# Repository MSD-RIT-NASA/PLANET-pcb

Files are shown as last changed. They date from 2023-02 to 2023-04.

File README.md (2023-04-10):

 

<!-- PROJECT SHIELDS -->
<!--
*** I'm using markdown "reference style" links for readability.
*** Reference links are enclosed in brackets [ ] instead of parentheses ( ).
*** See the bottom of this document for the declaration of the reference variables
*** for contributors-url, forks-url, etc. This is an optional, concise syntax you may use.
*** https://www.markdownguide.org/basic-syntax/#reference-style-links
-->

<!-- PROJECT LOGO -->
<br />
<div align="center">
  <a href="">
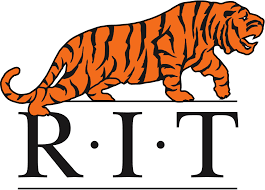
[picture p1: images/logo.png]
    
  </a>

  <h3 align="center">PLANETS PCB</h3>

  <p align="center">
    The pcb for the connector board. This is to negate the excess use of wires and fit snuggly into the case.
  </p>
</div>

<!-- TABLE OF CONTENTS -->
<details>
  <summary>Table of Contents</summary>
  <ol>
    <li>
      <a href="#about-the-project">About The Project</a>
      <ul>
        <li><a href="#built-with">Built With</a></li>
      </ul>
    </li>
    <li><a href="#Component List">Component List</a></li>
    <li><a href="#block-diagram">Block Diagram</a></li>
    <li><a href="#schematic">Schematic</a></li>
    <li><a href="#pcb-layout">PCB Layout</a></li>
    <li><a href="#dimensions">Dimensions</a></li>
    <li><a href="#order details">Order Details</a></li>
    <li><a href="#contact">Contact</a></li>
  </ol>
</details>

<!-- ABOUT THE PROJECT -->
## About the Project

Project Link: [https://github.com/MSD-RIT-NASA](https://github.com/MSD-RIT-NASA)

This PCB was created for the intention to be used with the Gamification and Performanced Based Monitoring of Sensorimotor Activities project with NASA. This project, also known as PLANETs, is being developed by a Multidiciplinary Team at RIT. The objective of the project is to train an astronauts sense of blance when they return from long suspended time in space or to adapt themselves to a new planet's gravity. The game was meant to be a fun and competitive way to train the balance and activly collect and calculate data on their performace. These sensors interface with the SlimeVR program to create a skeleton that configures a persons center of balance, and creates a score. Another sensor is used under a balance board to relay the rotation of the board to the game. The game reflects a position back to the player in order to encourage them to adjust the angle of the balance board according to the game. The game awards the adjusted balance with game points, and negates points when they do not accuratly move the board. 

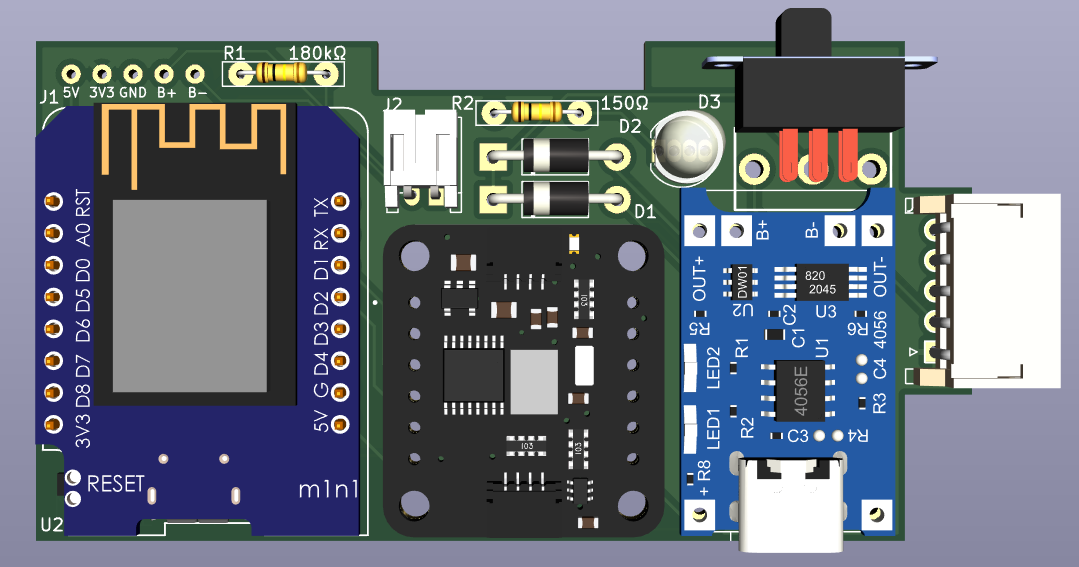
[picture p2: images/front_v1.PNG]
Front of PCB
[]()
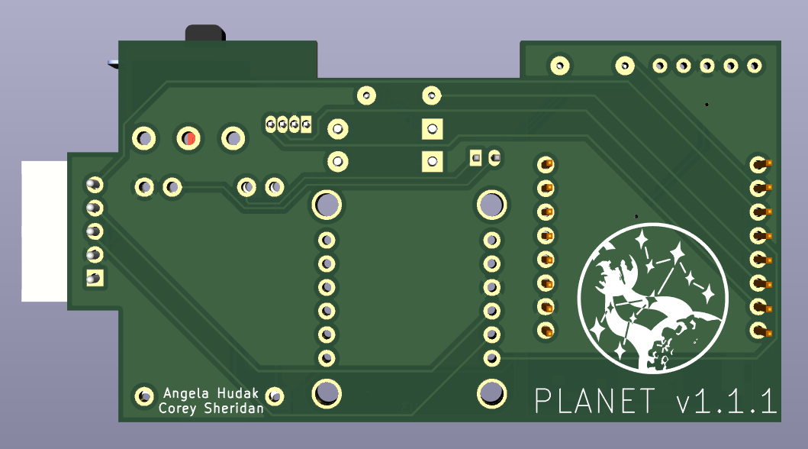
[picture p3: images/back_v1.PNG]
Back of PCB
[]()

<p align="right">(<a href="#top">back to top</a>)</p>

### Built With

The pcb and schematic were designed in KiCad and ordered on JLCPCB

* [KiCad](https://www.kicad.org/)
* [JLCPCB](https://jlcpcb.com/)

<p align="right">(<a href="#top">back to top</a>)</p>

<!-- Component List -->
## Component List

Name | Symbol | Footprint | Purchase Link
--- | --- | --- | ---
RGB LED | Device:LED_RGBK | LED_THT:LED_D5.0mm-4_RGB | [LINK](https://www.sparkfun.com/products/9264)
150Ω | Device:R | 150Ω | [LINK](https://www.amazon.com/BOJACK-Values-Resistor-Resistors-Assortment/dp/B08FD1XVL6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)
180KΩ | Device:R | 180KΩ | [LINK](https://www.digikey.com/en/products/detail/te-connectivity-passive-product/ROX3SJ180K/2390251)
3.7V Lipo Battery| --- | --- | [LINK](https://www.digikey.com/en/products/detail/jauch-quartz/LP503759JU-PCM-2-WIRES-70MM/9560991)
Battery Connector | Connector:Conn_01x02_Female | JST_PH_S2B-PH-K_02x2.00mm_Angled | [LINK](https://www.digikey.com/en/products/detail/jst-sales-america-inc/S2B-PH-K-S-LF-SN/926626) [LINK](https://www.digikey.com/en/products/detail/jst-sales-america-inc/PHR-2/608607)
1N5817 Diode | SlimeVRMotherBoard-cache:Diode_1N5817 | Diode_THT:D_DO-41_SOD81_P10.16mm_Horizontal | [LINK](https://www.digikey.com/en/products/detail/stmicroelectronics/1N5817/770971)
1N5817 Diode | SlimeVRMotherBoard-cache:Diode_1N5817 | Diode_THT:D_DO-41_SOD81_P10.16mm_Horizontal | [LINK](https://www.digikey.com/en/products/detail/stmicroelectronics/1N5817/770971)
TP4056 Type-C | SlimeVRLibrary:4056Board | 4056Board | [LINK](https://www.amazon.com/gp/product/B07PZ6V937/ref=ppx_yo_dt_b_search_asin_title?ie=UTF8&psc=1)
Switch | SlimeVRLibrary:SlideSwitch | Wowoone_Slide_Switch_5mm | [LINK](https://www.amazon.com/gp/product/B07XSJYYYB/ref=ppx_yo_dt_b_search_asin_title?ie=UTF8&psc=1)
D1 mini | wemos_mini:WeMos_D1_mini | wemos-d1-mini-with-pin-header-and-connector | [LINK](https://www.amazon.com/gp/product/B081PX9YFV/ref=ppx_yo_dt_b_asin_title_o02_s00?ie=UTF8&th=1)
BNO085 Sensor | BNO085:4754 | BNO085 | [LINK](https://www.digikey.com/en/products/detail/adafruit-industries-llc/4754/13426653)
BNO085 AUX Sensor Connector | Connector:Conn_01x05_Female | JST_XH_S05B-XH-A_05x2.50mm_Angled | [LINK](https://www.digikey.com/en/products/detail/jst-sales-america-inc./S5B-XH-A-1(LF)(SN)/9961924) [LINK](https://www.digikey.com/en/products/detail/jst-sales-america-inc/XHP-5/1125486)
Status Rail Connector | Connector:Conn_01x05_Female | fivePinConn | ---

<p align="right">(<a href="#top">back to top</a>)</p>

<!-- BLOCK DIAGRAM -->
## Block Diagram
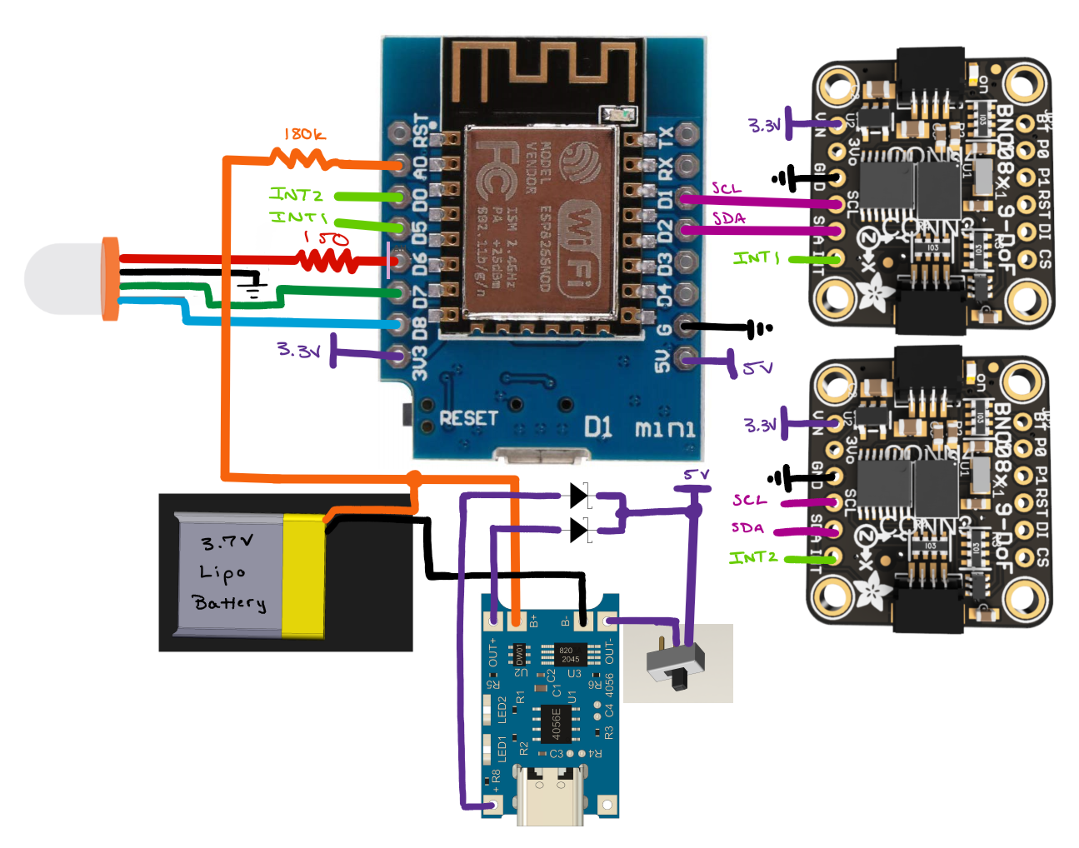
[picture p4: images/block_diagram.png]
Block Diagram
[]()

<!-- SCHEMATIC -->
## Schematic
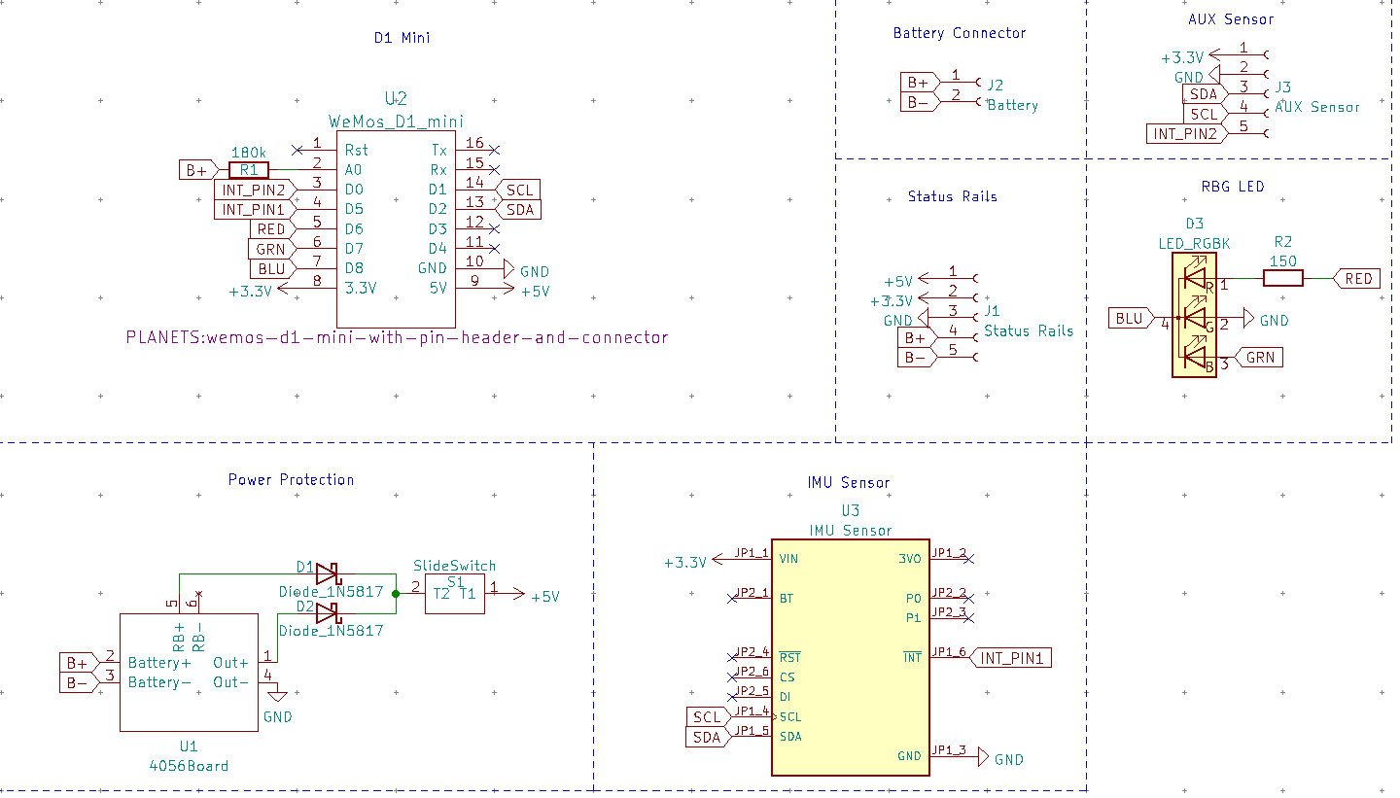
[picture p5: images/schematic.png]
schematic
[]()

<!-- PCB LAYOUT -->
## PCB Layout
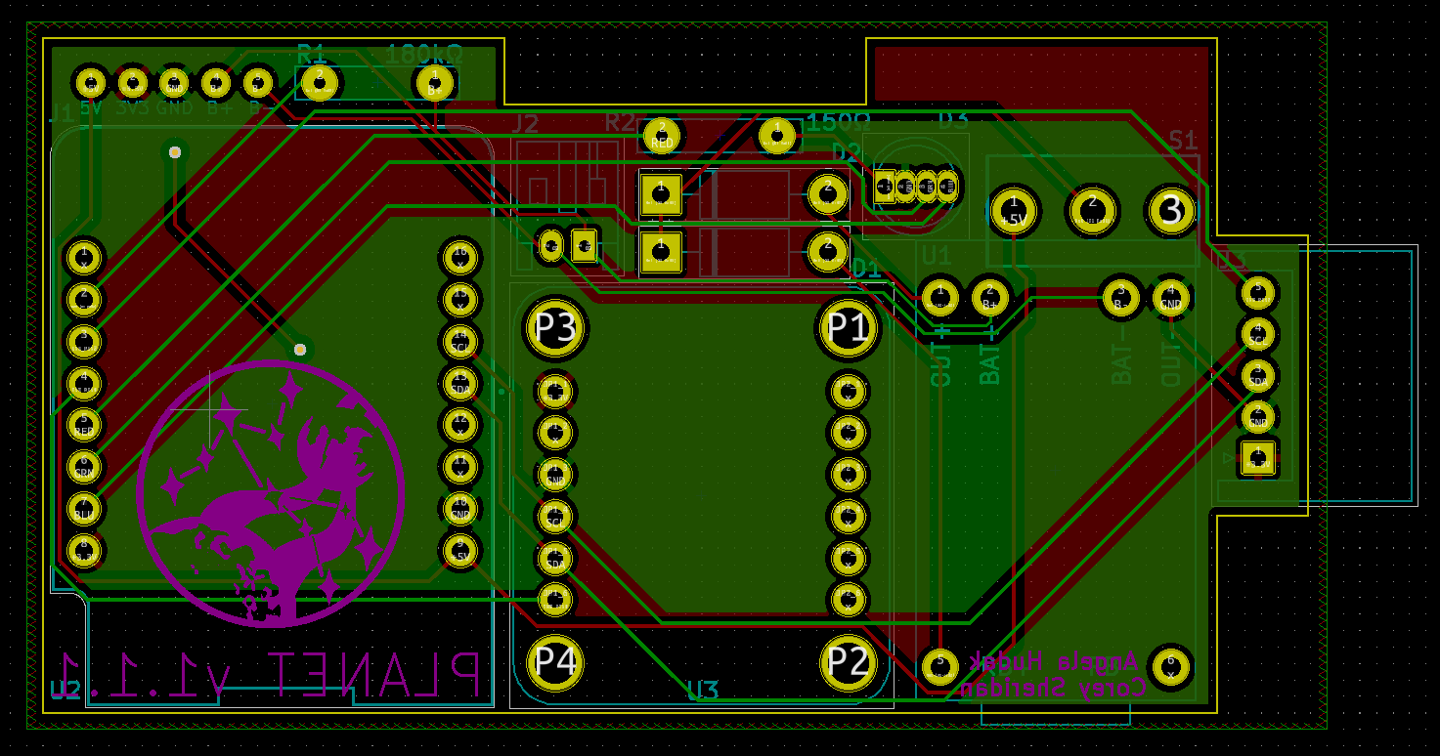
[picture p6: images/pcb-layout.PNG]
pcb-layout
[]()

<!-- DIMENSIONS -->
## Dimensions

PCB Dimensions: 71.394mm x 41.148mm

<!-- Order Details -->
## Order Details
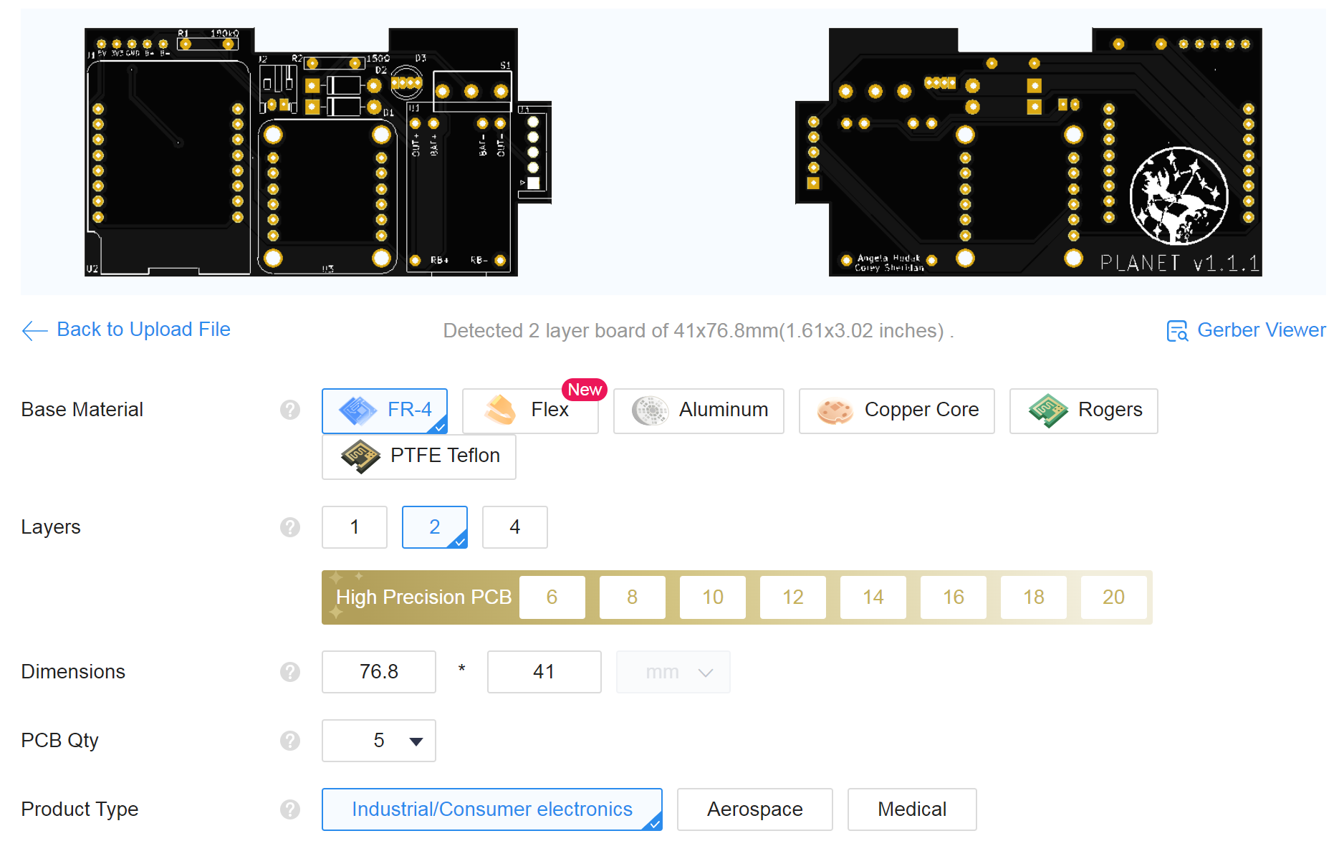
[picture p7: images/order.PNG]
order1
[]()
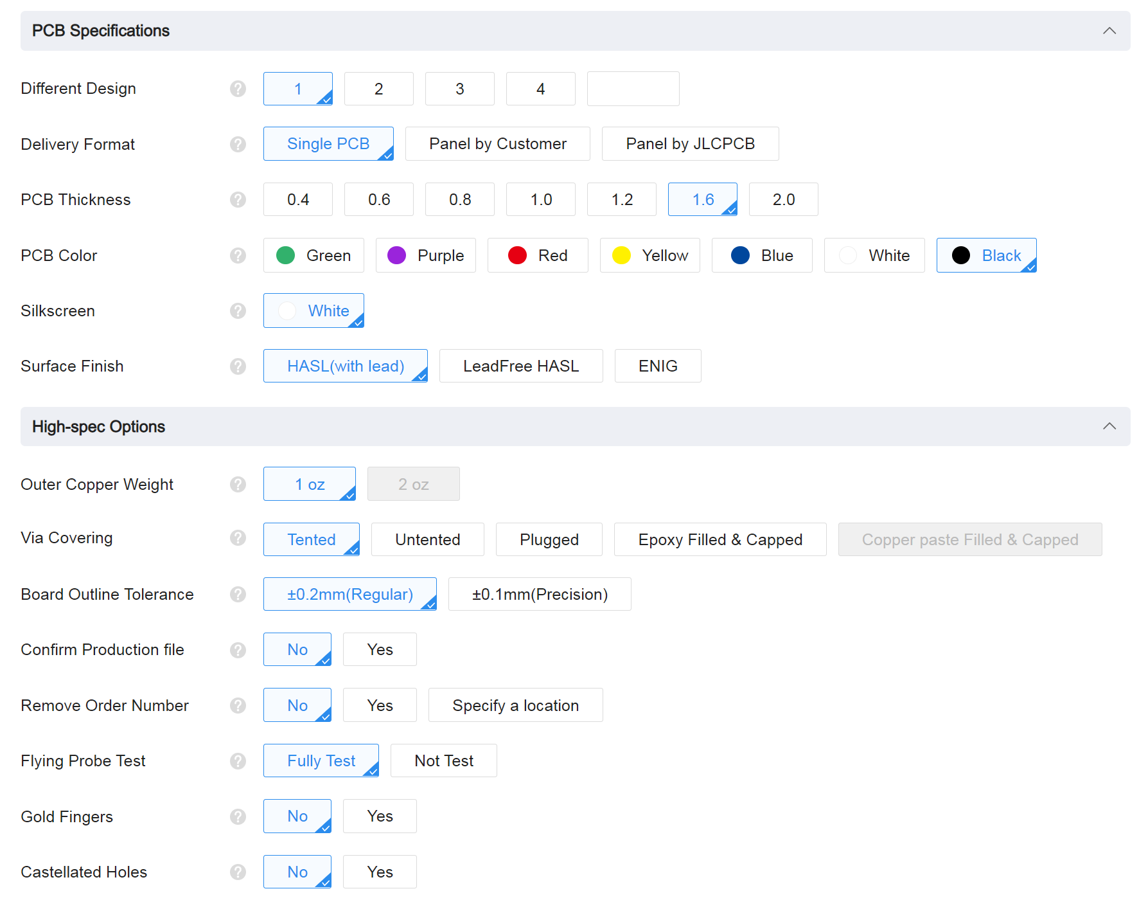
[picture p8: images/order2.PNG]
order2
[]()

Note: A non-green (in this case, black) PCB takes shipping 2 days longer

<!-- CONTACT -->
## Contact
Name | Major | email | github | year
--- | --- | --- | --- | ---
Angela Hudak | CE | ach2414@rit.edu | angelahudak | 2023
Corey Sheridan | CE | cjs5445@rit.edu | cjs5445 | 2023

<!-- MARKDOWN LINKS & IMAGES -->
<!-- https://www.markdownguide.org/basic-syntax/#reference-style-links -->

[block-diagram]: images/block_diagram.png
[schematic]: images/schematic.png
[front-3dview]: images/front_v1.PNG
[back-3dview]: images/back_v1.PNG
[order1]: images/order.PNG
[order2]: images/order2.PNG
[pcb-layout]: images/pcb-layout.PNG

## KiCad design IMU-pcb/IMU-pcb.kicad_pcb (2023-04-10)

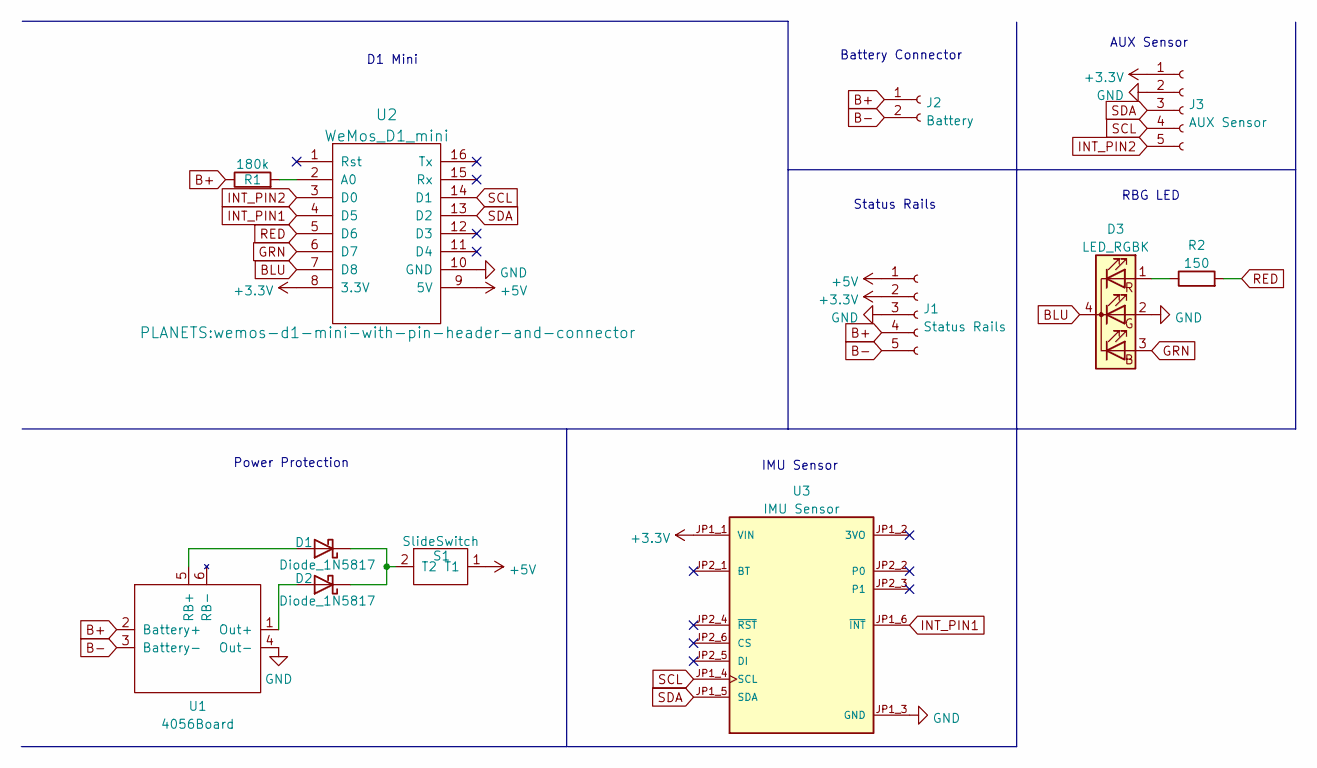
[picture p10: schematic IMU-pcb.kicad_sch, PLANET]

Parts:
D1, D2: Diode_1N5817; D_DO-41_SOD81_P10.16mm_Horizontal
D3: LED_RGBK; LED_D5.0mm-4_RGB
J1: Status Rails; fivePinConn
J2: Battery; JST_PH_S2B-PH-K_02x2.00mm_Angled
J3: AUX Sensor; JST_XH_S05B-XH-A_05x2.50mm_Angled
R1: 180k; 180KOhm
R2: 150; 150Ohm
S1: SlideSwitch; Wowoone_Slide_Switch_5mm
U1: 4056Board
U2: WeMos_D1_mini; wemos-d1-mini-with-pin-header-and-connector
U3: IMU Sensor; BNO085; PARTREV 2021-03-16

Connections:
+3.3V: J1.2, J3.1, U2.8 (3.3V), U3.JP1_1 (VIN)
+5V: J1.1, S1.1 (T1), U2.9 (5V)
B+: J1.4, J2.1, R1.1, U1.2 (Battery+)
B-: J1.5, J2.2, U1.3 (Battery-)
BLU: D3.4 (K), U2.7 (D8)
GND: D3.2 (GA), J1.3, J3.2, U1.4 (Out-), U2.10 (GND), U3.JP1_3 (GND)
GRN: D3.3 (BA), U2.6 (D7)
INT_PIN1: U2.4 (D5), U3.JP1_6 (~INT)
INT_PIN2: J3.5, U2.3 (D0)
unnamed: D1.1 (K), D2.1 (K), S1.2 (T2)
unnamed: D1.2 (A), U1.5 (RB+)
unnamed: D2.2 (A), U1.1 (Out+)
unnamed: D3.1 (RA), R2.1
unnamed: R1.2, U2.2 (A0)
RED: R2.2, U2.5 (D6)
SCL: J3.4, U2.14 (D1), U3.JP1_4 (SCL)
SDA: J3.3, U2.13 (D2), U3.JP1_5 (SDA)

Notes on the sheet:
RBG LED
Status Rails
IMU Sensor
Battery Connector
Power Protection
D1 Mini
AUX Sensor

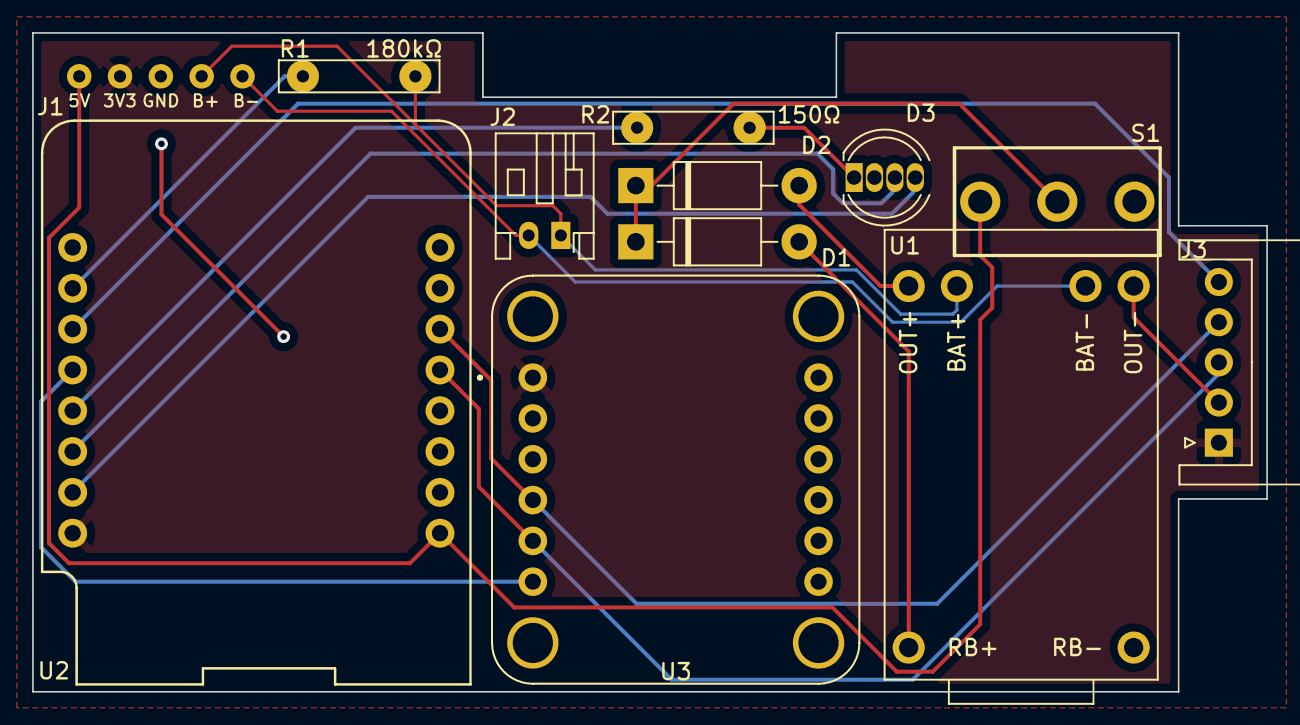
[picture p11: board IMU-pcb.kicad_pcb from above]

Board: 2 copper layers, 76.8 x 41.0 mm, 12 parts (0 on the bottom side), 17 nets.

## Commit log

2023-02-02 Schematic image
2023-02-02 Adding schematic to README
2023-02-08 completed Schematic and started PCB Layout
    [IMU-pcb.kicad_pcb, IMU-pcb.kicad_sch]
2023-02-13 formalized schematic, symbols, and footprints
    [IMU-pcb.kicad_pcb, IMU-pcb.kicad_sch]
2023-02-14 Starting pcb layout
    [IMU-pcb.kicad_pcb]
2023-02-14 Adjusting pcb layout to fit for the dimensions
    [IMU-pcb.kicad_pcb]
2023-02-17 working on desktop
    [IMU-pcb.kicad_pcb, IMU-pcb.kicad_sch]
2023-02-17 Finished PCB layout and gerbers
    [IMU-pcb-B_Cu.gbl, IMU-pcb-B_Mask.gbs, IMU-pcb-B_Paste.gbp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]
2023-02-26 Finished v1.1 layout
    [IMU-pcb.kicad_pcb, IMU-pcb.kicad_sch]
2023-02-27 Adjusted pcb layout to be better
    [IMU-pcb-B_Cu.gbl, IMU-pcb-B_Mask.gbs, IMU-pcb-B_Paste.gbp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]
2023-03-31 adding 3D models for readme pic
    [IMU-pcb.kicad_pcb]
2023-03-31 adjusted 3d shapes
    [IMU-pcb.kicad_pcb]
2023-04-10 new version of PCB
    [IMU-pcb-B_Cu.gbl, IMU-pcb-B_Mask.gbs, IMU-pcb-B_Paste.gbp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]
2023-04-10 organzied gerbers
    [IMU-pcb-B_Cu.gbl, IMU-pcb-B_Mask.gbs, IMU-pcb-B_Paste.gbp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]
